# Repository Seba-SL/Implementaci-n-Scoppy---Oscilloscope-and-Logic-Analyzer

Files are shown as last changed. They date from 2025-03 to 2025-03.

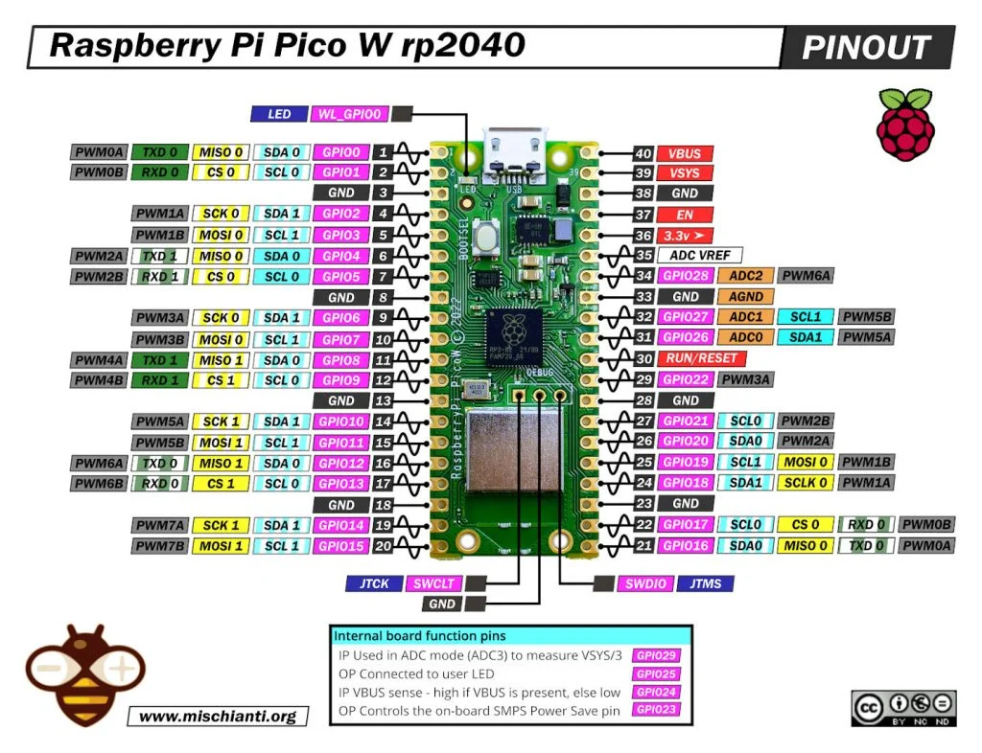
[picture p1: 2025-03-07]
Hojas de Datos/pinoutRaspberryWpico.jpg

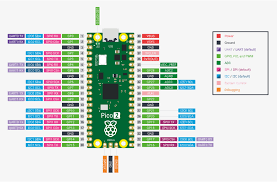
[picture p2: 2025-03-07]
Hojas de Datos/pinoutPico.png

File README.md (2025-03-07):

<h1> imagen Implementación Scoppy - Oscilloscope and Logic Analyzer </h1>

Fuente: https://oscilloscope.fhdm.xyz/

En este repositorio se implementa el diseño N° 5 de el proyecho Scoppy para Raspberry Pico W de microcontrolador RP2040.

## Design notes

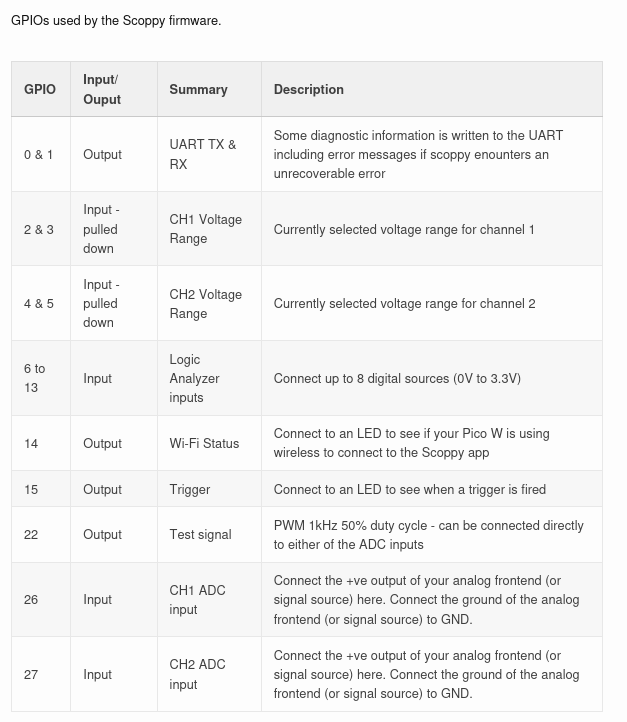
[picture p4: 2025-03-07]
Hojas de Datos/pinoutScoppy.png

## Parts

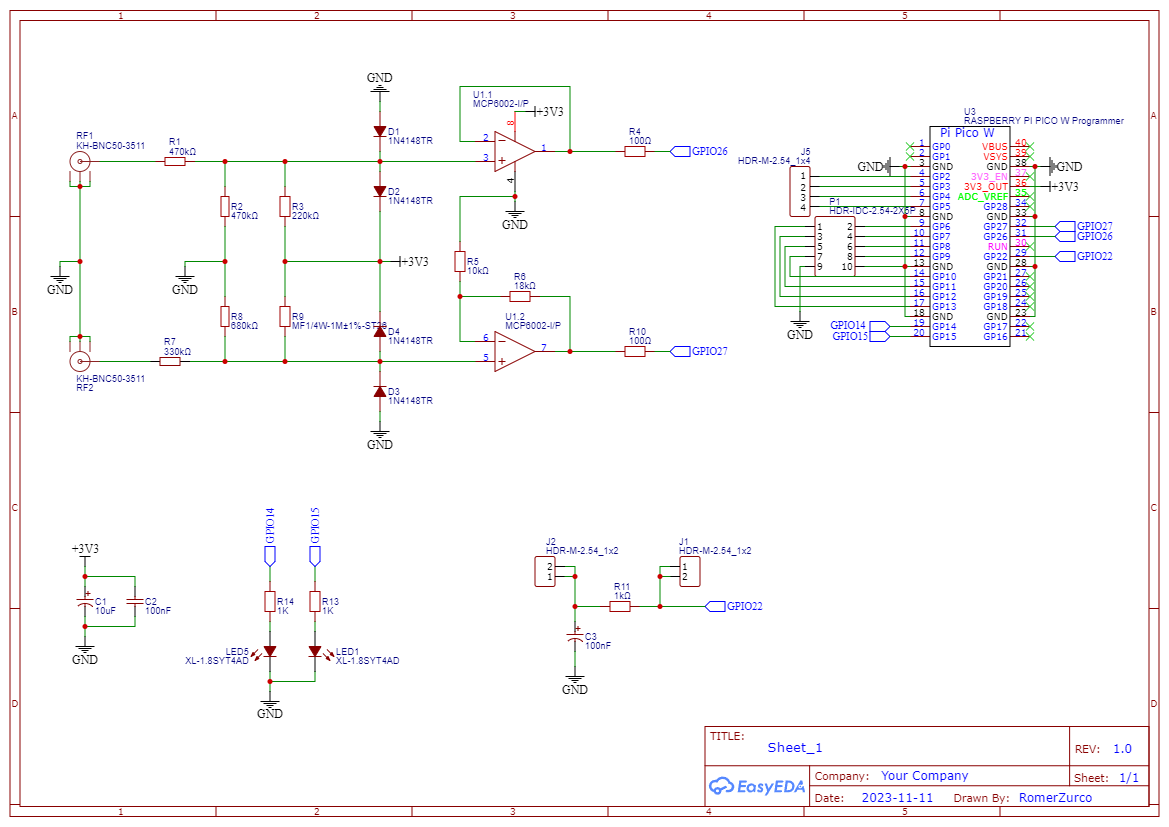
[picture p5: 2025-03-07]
Schematic_Osciloscopio_Low_Cost_Pico_2023-11-28.png

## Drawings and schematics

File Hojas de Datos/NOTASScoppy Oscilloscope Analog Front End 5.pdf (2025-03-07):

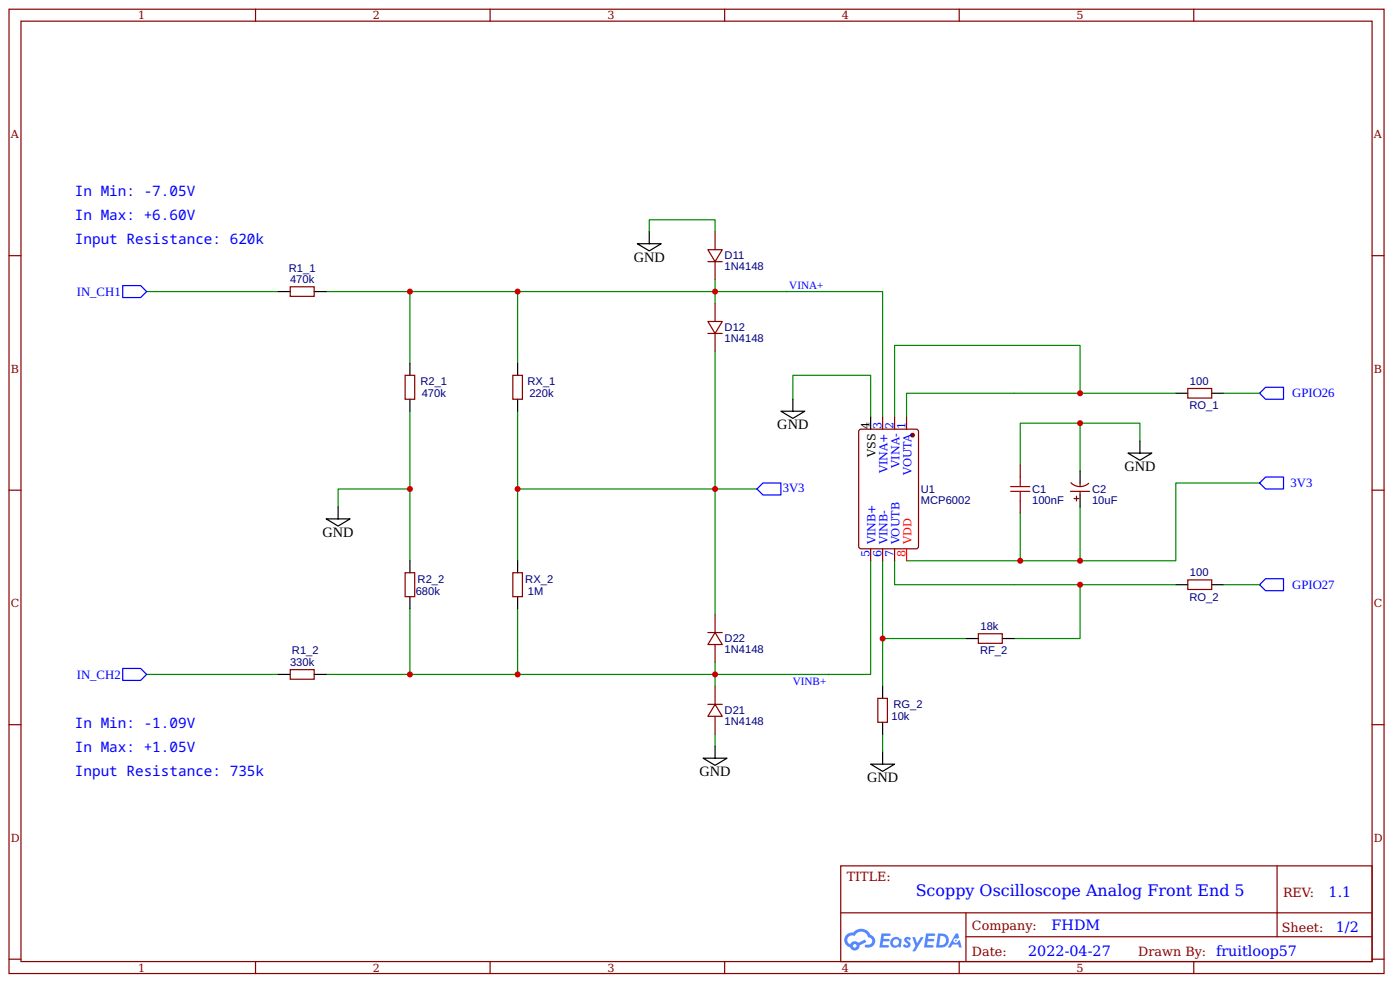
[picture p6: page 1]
Input Resistance: 620k; Input Resistance: 735k; GND; In Max: +1.05V; In Min: -1.09V; In Max: +6.60V; In Min: -7.05V; VINA+; VINB+; GPIO27; GPIO26; MCP6002; TITLE:; Scoppy Oscilloscope Analog Front End 5; REV: 1.1; Date:; Sheet: 1/2; Drawn By: fruitloop57; Company: FHDM

VOUTA 1 VINA- 2 VINA+ 3 VSS 4 VINB+ 5 VINB- 6 VOUTB 7 VDD 8

## Examples of other voltage ranges

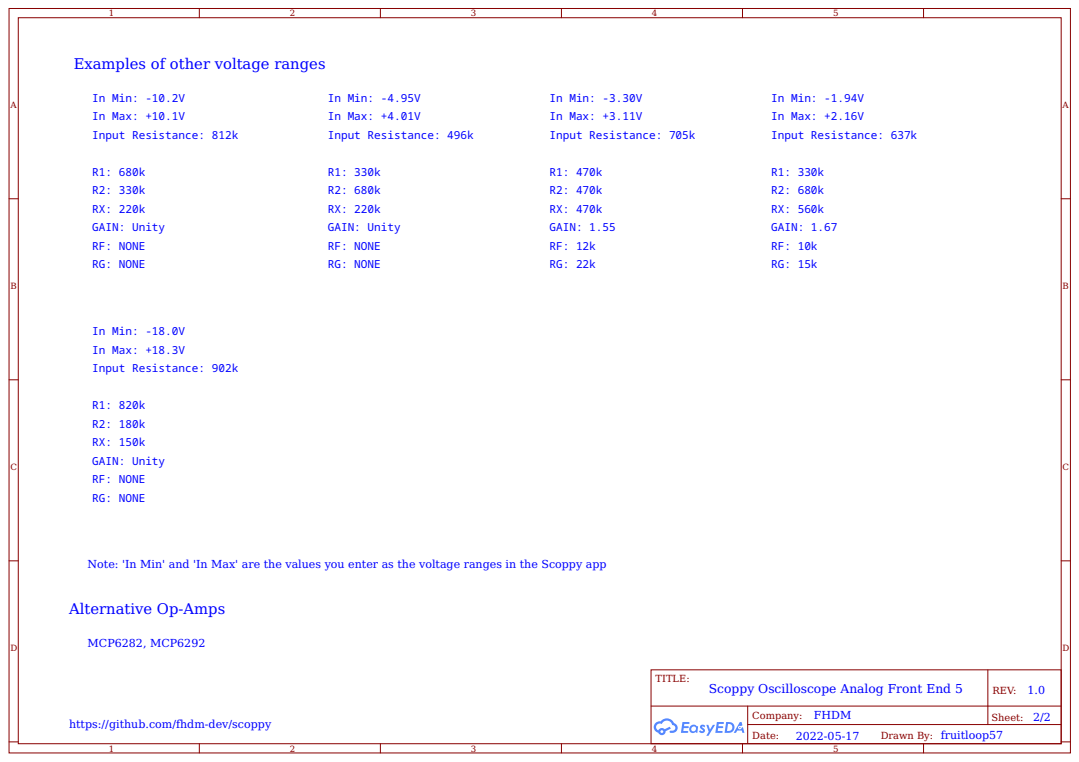
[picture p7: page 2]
MCP6282, MCP6292; GAIN: 1.67; In Min: -10.2V; In Max: +10.1V; Input Resistance: 812k; GAIN: Unity; RF: NONE; RG: NONE; Input Resistance: 637k; In Max: +2.16V; In Min: -1.94V; GAIN: 1.55; Input Resistance: 705k; In Max: +3.11V; In Min: -3.30V; Input Resistance: 496k; In Max: +4.01V; In Min: -4.95V A; TITLE:; Scoppy Oscilloscope Analog Front End 5; REV: 1.0; Date:; Sheet: 2/2; Drawn By: fruitloop57; Input Resistance: 902k; In Max: +18.3V; In Min: -18.0V

Note: 'In Min' and 'In Max' are the values you enter as the voltage ranges in the Scoppy app

Alternative Op-Amps

Company: FHDM https://github.com/fhdm-dev/scoppy

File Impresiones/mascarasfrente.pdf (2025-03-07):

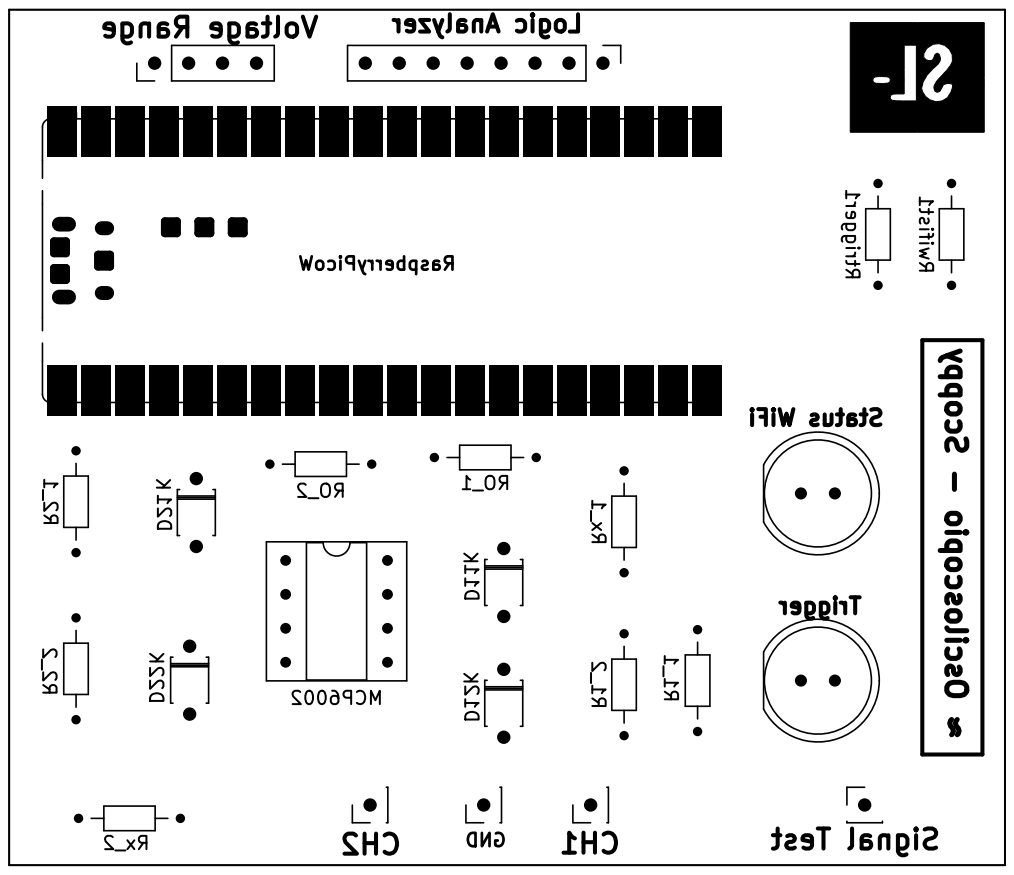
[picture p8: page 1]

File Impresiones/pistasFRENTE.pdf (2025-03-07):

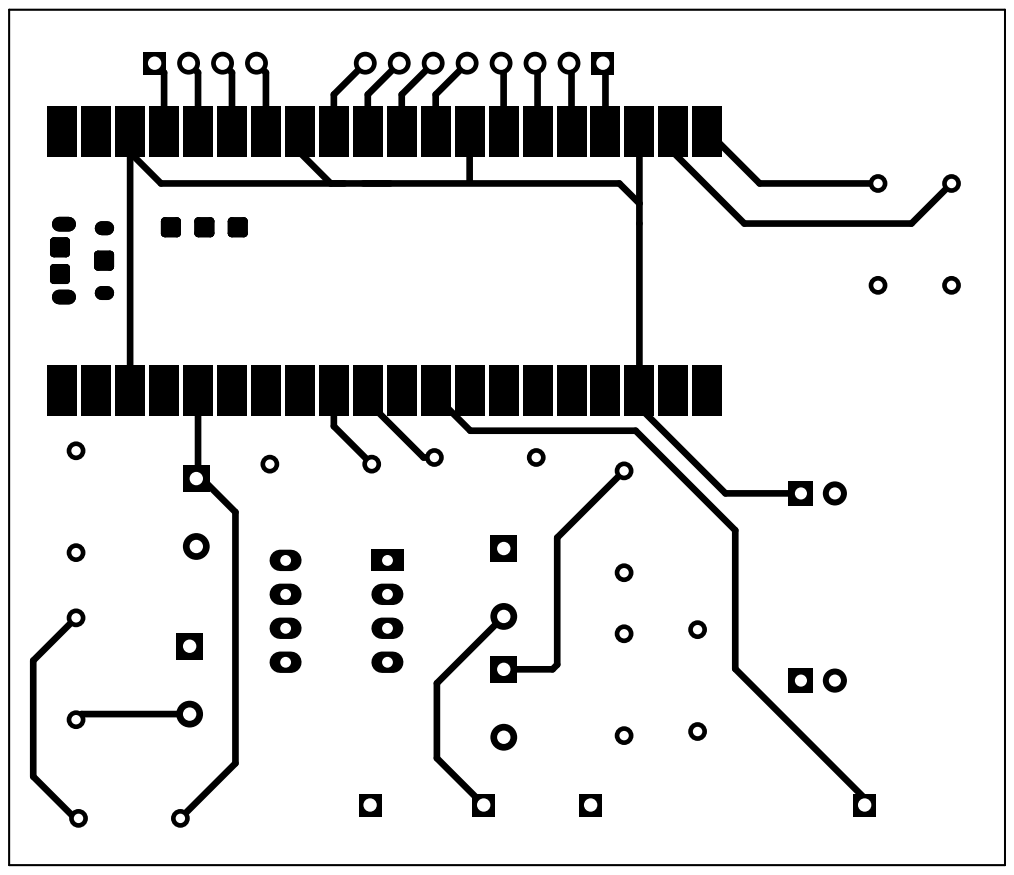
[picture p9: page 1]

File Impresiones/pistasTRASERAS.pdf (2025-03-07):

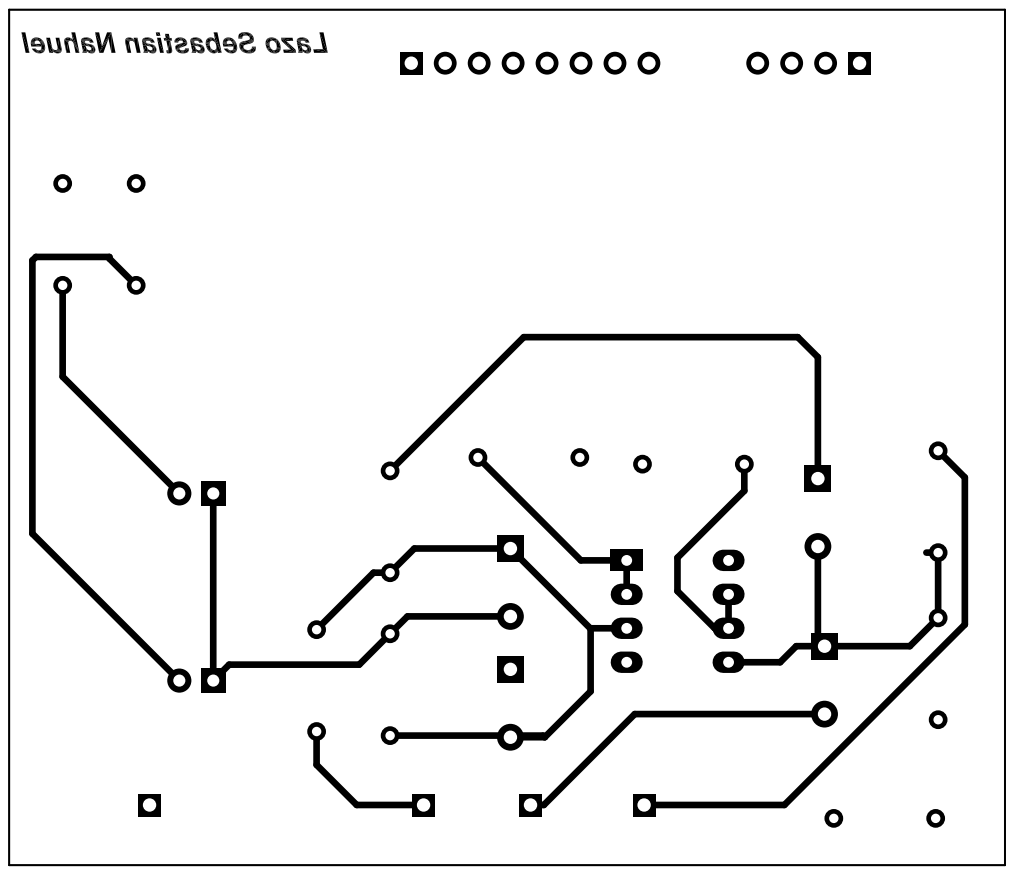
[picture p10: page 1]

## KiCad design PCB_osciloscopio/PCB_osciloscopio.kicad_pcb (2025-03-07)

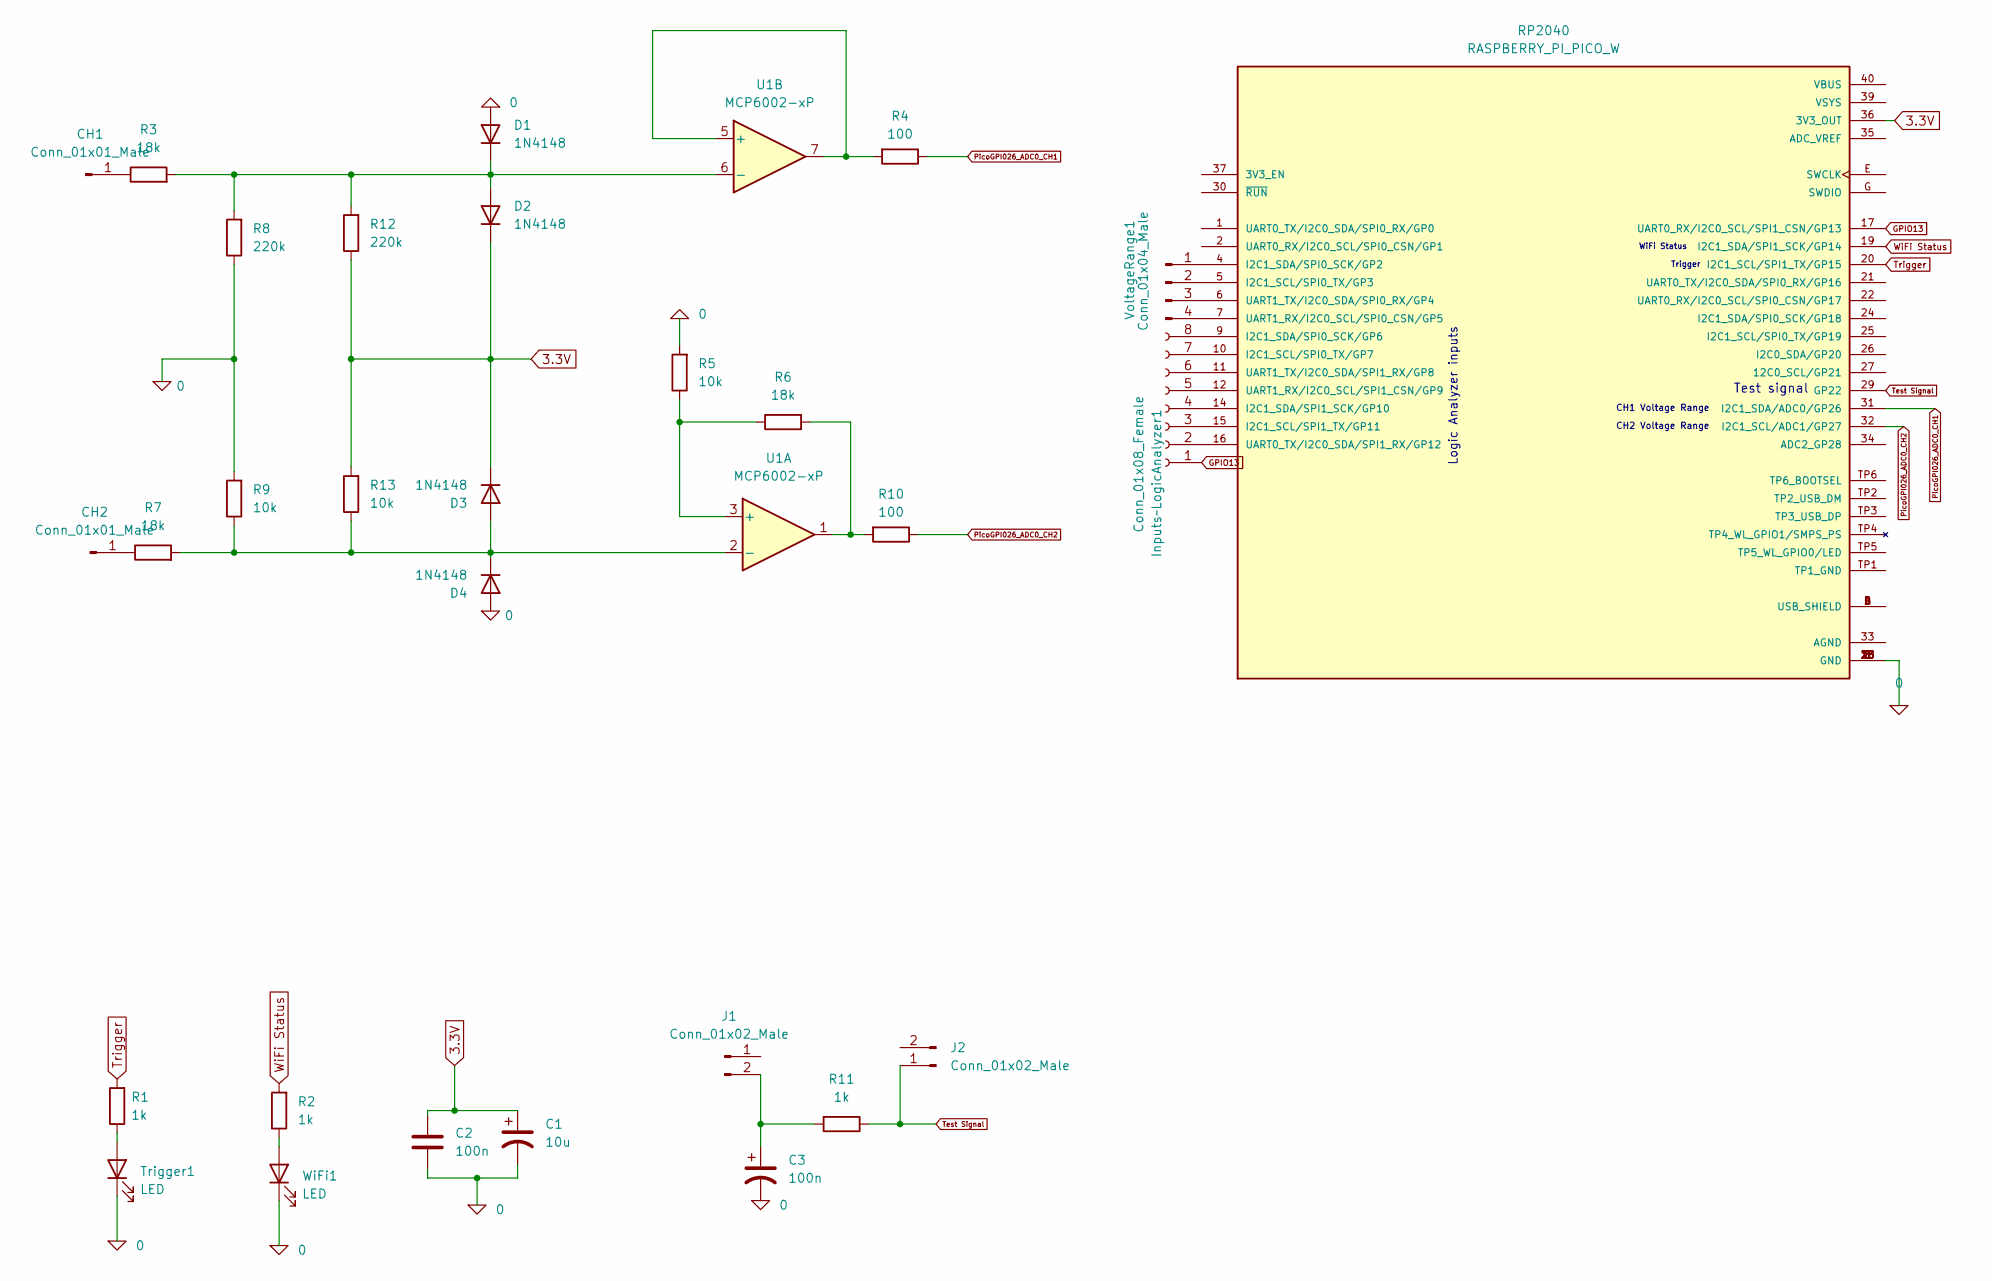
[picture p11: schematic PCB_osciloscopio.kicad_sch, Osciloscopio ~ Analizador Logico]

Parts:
C1: 10u; CP_Radial_D4.0mm_P1.50mm
C2: 100n; CP_Radial_D4.0mm_P1.50mm
C3: 100n; CP_Radial_D4.0mm_P2.00mm
CH1, CH2: Conn_01x01_Male; PinHeader_1x01_P1.00mm_Vertical
D1, D2, D3, D4: 1N4148; D_DO-35_SOD27_P7.62mm_Horizontal
Inputs~LogicAnalyzer1: Conn_01x08_Female; PinSocket_1x08_P2.54mm_Vertical
J1, J2: Conn_01x02_Male; PinHeader_1x02_P2.00mm_Vertical
R1, R2, R11: 1k; R_Axial_DIN0204_L3.6mm_D1.6mm_P7.62mm_Horizontal
R3, R6, R7: 18k; R_Axial_DIN0204_L3.6mm_D1.6mm_P7.62mm_Horizontal
R4, R10: 100; R_Axial_DIN0204_L3.6mm_D1.6mm_P7.62mm_Horizontal
R5, R9, R13: 10k; R_Axial_DIN0204_L3.6mm_D1.6mm_P7.62mm_Horizontal
R8, R12: 220k; R_Axial_DIN0204_L3.6mm_D1.6mm_P7.62mm_Horizontal
RP2040: RASPBERRY_PI_PICO_W; MODULE_RASPBERRY_PI_PICO_W; PARTREV 2.4
Trigger1: LED; LED_D3.0mm
U1: MCP6002-xP; DIP-8_W10.16mm_LongPads
VoltageRange1: Conn_01x04_Male; PinHeader_1x04_P2.00mm_Vertical
WiFi1: LED; LED_D3.0mm

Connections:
0: C1.2, C2.2, C3.2, D1.2 (A), D4.2 (A), R5.2, R8.1, R9.2, RP2040.3 (GND), RP2040.8 (GND), RP2040.13 (GND), RP2040.18 (GND), RP2040.23 (GND), RP2040.28 (GND), RP2040.38 (GND), RP2040.F (GND), Trigger1.1 (K), WiFi1.1 (K)
3.3V: C1.1, C2.1, D2.1 (K), D3.1 (K), R12.1, R13.2, RP2040.36 (3V3_OUT)
GPIO13: Inputs~LogicAnalyzer1.1, RP2040.17 (UART0_RX/I2C0_SCL/SPI1_CSN/GP13)
unnamed: C3.1, J1.2, R11.2
unnamed: CH1.1, R3.1
unnamed: CH2.1, R7.1
unnamed: D1.1 (K), D2.2 (A), R3.2, R8.2, R12.2, U1.6 (-)
unnamed: D3.2 (A), D4.1 (K), R7.2, R9.1, R13.1, U1.2 (-)
unnamed: Inputs~LogicAnalyzer1.2, RP2040.16 (UART0_TX/I2C0_SDA/SPI1_RX/GP12)
unnamed: Inputs~LogicAnalyzer1.3, RP2040.15 (I2C1_SCL/SPI1_TX/GP11)
unnamed: Inputs~LogicAnalyzer1.4, RP2040.14 (I2C1_SDA/SPI1_SCK/GP10)
unnamed: Inputs~LogicAnalyzer1.5, RP2040.12 (UART1_RX/I2C0_SCL/SPI1_CSN/GP9)
unnamed: Inputs~LogicAnalyzer1.6, RP2040.11 (UART1_TX/I2C0_SDA/SPI1_RX/GP8)
unnamed: Inputs~LogicAnalyzer1.7, RP2040.10 (I2C1_SCL/SPI0_TX/GP7)
unnamed: Inputs~LogicAnalyzer1.8, RP2040.9 (I2C1_SDA/SPI0_SCK/GP6)
unnamed: R1.1, Trigger1.2 (A)
unnamed: R2.1, WiFi1.2 (A)
unnamed: R4.2, U1.5 (+), U1.7
unnamed: R5.1, R6.1, U1.3 (+)
unnamed: R6.2, R10.2, U1.1
unnamed: RP2040.4 (I2C1_SDA/SPI0_SCK/GP2), VoltageRange1.1
unnamed: RP2040.5 (I2C1_SCL/SPI0_TX/GP3), VoltageRange1.2
unnamed: RP2040.6 (UART1_TX/I2C0_SDA/SPI0_RX/GP4), VoltageRange1.3
unnamed: RP2040.7 (UART1_RX/I2C0_SCL/SPI0_CSN/GP5), VoltageRange1.4
unnamed: RP2040.A (USB_SHIELD), RP2040.B (USB_SHIELD), RP2040.C (USB_SHIELD), RP2040.D (USB_SHIELD)
PicoGPI026_ADC0_CH1: R4.1, RP2040.31 (I2C1_SDA/ADC0/GP26)
PicoGPI026_ADC0_CH2: R10.1, RP2040.32 (I2C1_SCL/ADC1/GP27)
Test Signal: J2.1, R11.1, RP2040.29 (GP22)
Trigger: R1.2, RP2040.20 (I2C1_SCL/SPI1_TX/GP15)
WiFi Status: R2.2, RP2040.19 (I2C1_SDA/SPI1_SCK/GP14)

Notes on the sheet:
CH1 Voltage Range
CH2 Voltage Range
Test signal
Trigger
Logic Analyzer inputs
WiFi Status

Board: 2 copper layers, 30 parts (0 on the bottom side), 30 nets, no tracks yet.

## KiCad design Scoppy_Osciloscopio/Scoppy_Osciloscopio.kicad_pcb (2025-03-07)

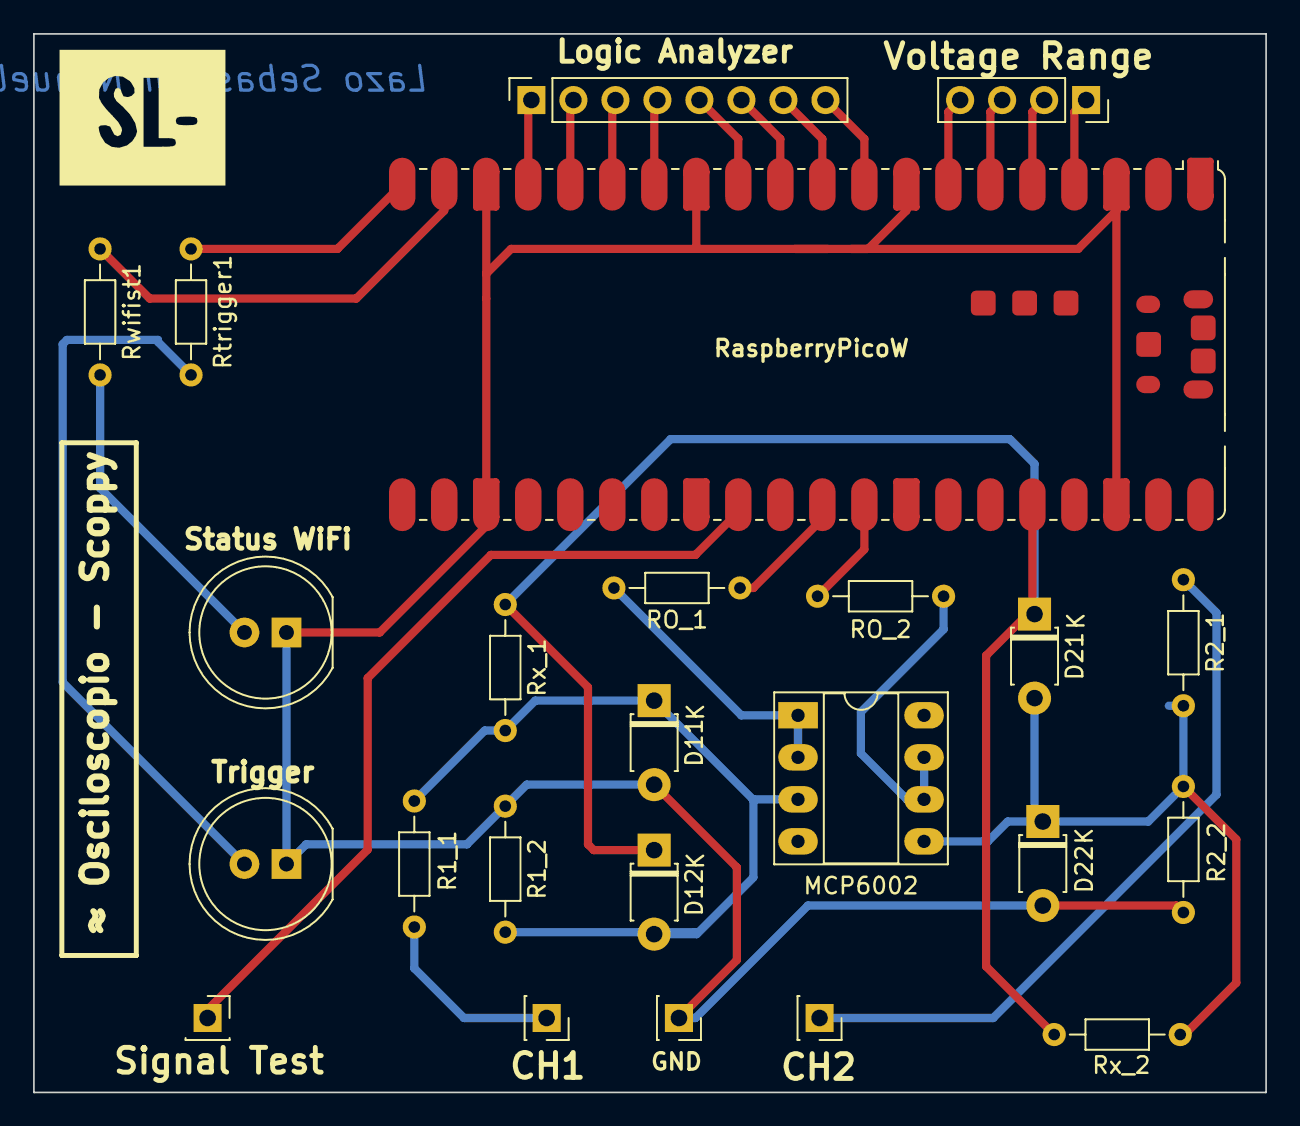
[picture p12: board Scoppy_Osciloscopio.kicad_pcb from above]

Board: 2 copper layers, 74.5 x 64.0 mm, 24 parts (0 on the bottom side), 27 nets.

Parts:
CH1: CH1_input; PinSocket_1x01_P2.54mm_Vertical
CH2: CH2_input; PinSocket_1x01_P2.54mm_Vertical
D11, D12, D21, D22: 1N4148; D_T-1_P5.08mm_Horizontal
GND: GND; PinSocket_1x01_P2.54mm_Vertical
Logic Analyzer: LogicAnalizer; PinSocket_1x08_P2.54mm_Vertical
MCP6002: MCP6002-xP; DIP-8_W7.62mm_Socket_LongPads
R1_1, R2_1: 680k; R_Axial_DIN0204_L3.6mm_D1.6mm_P7.62mm_Horizontal
R1_2, R2_2: 330k; R_Axial_DIN0204_L3.6mm_D1.6mm_P7.62mm_Horizontal
RO_1, RO_2: 100; R_Axial_DIN0204_L3.6mm_D1.6mm_P7.62mm_Horizontal
RaspberryPicoW: RASPBERRY_PI_PICO_W; RaspberryPi_Pico_W_SMD
Rtrigger1: 1k; R_Axial_DIN0204_L3.6mm_D1.6mm_P7.62mm_Horizontal
Rwifist1: 1k; R_Axial_DIN0204_L3.6mm_D1.6mm_P7.62mm_Horizontal
Rx_1, Rx_2: 220k; R_Axial_DIN0204_L3.6mm_D1.6mm_P7.62mm_Horizontal
Signal Test: SignalTest; PinSocket_1x01_P2.54mm_Vertical
Status WiFi: LED; LED_D8.0mm
Trigger: LED; LED_D8.0mm
Voltage Range: VoltageRange; PinSocket_1x04_P2.54mm_Vertical

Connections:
0: D11.2 (A), D22.2 (A), GND.1, R1_2.1, R2_2.1, RaspberryPicoW.3 (GND), RaspberryPicoW.8 (GND), RaspberryPicoW.13 (GND), RaspberryPicoW.18 (GND), RaspberryPicoW.23 (GND), RaspberryPicoW.28 (GND), RaspberryPicoW.38 (GND), Status WiFi.1 (K), Trigger.1 (K)
3,3V: D12.1 (K), D21.1 (K), RaspberryPicoW.36 (3V3_OUT), Rx_1.1, Rx_2.1
CH1_input: CH1.1, R1_1.1
CH2_input: CH2.1, R2_1.1
GP13: Logic Analyzer.1, RaspberryPicoW.17 (UART0_RX/I2C0_SCL/SPI1_CSN/GP13)
GPIO26: RO_1.1, RaspberryPicoW.31 (I2C1_SDA/ADC0/GP26)
GPIO27: RO_2.1, RaspberryPicoW.32 (I2C1_SCL/ADC1/GP27)
unnamed: D11.1 (K), D12.2 (A), MCP6002.3 (+), R1_1.2, R1_2.2, Rx_1.2
unnamed: D21.2 (A), D22.1 (K), MCP6002.5 (+), R2_1.2, R2_2.2, Rx_2.2
unnamed: Logic Analyzer.2, RaspberryPicoW.16 (UART0_TX/I2C0_SDA/SPI1_RX/GP12)
unnamed: Logic Analyzer.3, RaspberryPicoW.15 (I2C1_SCL/SPI1_TX/GP11)
unnamed: Logic Analyzer.4, RaspberryPicoW.14 (I2C1_SDA/SPI1_SCK/GP10)
unnamed: Logic Analyzer.5, RaspberryPicoW.12 (UART1_RX/I2C0_SCL/SPI1_CSN/GP9)
unnamed: Logic Analyzer.6, RaspberryPicoW.11 (UART1_TX/I2C0_SDA/SPI1_RX/GP8)
unnamed: Logic Analyzer.7, RaspberryPicoW.10 (I2C1_SCL/SPI0_TX/GP7)
unnamed: Logic Analyzer.8, RaspberryPicoW.9 (I2C1_SDA/SPI0_SCK/GP6)
unnamed: RaspberryPicoW.5 (I2C1_SCL/SPI0_TX/GP3), Voltage Range.2
unnamed: RaspberryPicoW.4 (I2C1_SDA/SPI0_SCK/GP2), Voltage Range.1
unnamed: RaspberryPicoW.7 (UART1_RX/I2C0_SCL/SPI0_CSN/GP5), Voltage Range.4
unnamed: RaspberryPicoW.6 (UART1_TX/I2C0_SDA/SPI0_RX/GP4), Voltage Range.3
unnamed: Rwifist1.2, Status WiFi.2 (A)
unnamed: Rtrigger1.2, Trigger.2 (A)
unnamed: MCP6002.1, MCP6002.2 (-), RO_1.2
unnamed: MCP6002.6 (-), MCP6002.7, RO_2.2
Test Signal: RaspberryPicoW.29 (GP22), Signal Test.1
Trigger: RaspberryPicoW.20 (I2C1_SCL/SPI1_TX/GP15), Rtrigger1.1
WiFi-Status: RaspberryPicoW.19 (I2C1_SDA/SPI1_SCK/GP14), Rwifist1.1
